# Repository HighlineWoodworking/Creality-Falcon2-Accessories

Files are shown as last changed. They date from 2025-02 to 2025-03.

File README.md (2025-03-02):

# Creality-Falcon2-Accessories
Accessories for a [Creality Falcon2 Laser](https://www.creality.com/products/creality-falcon2-22w).

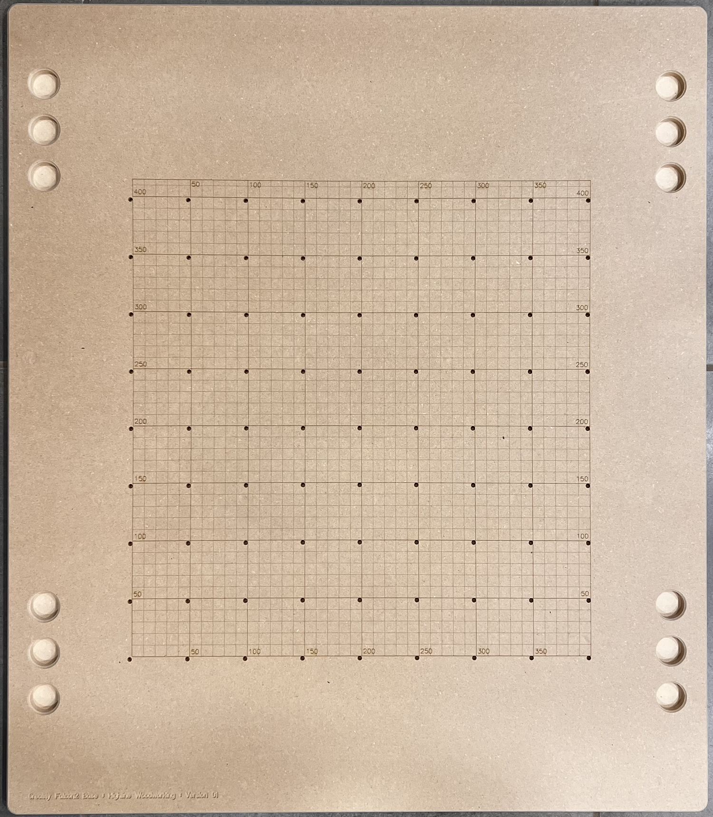
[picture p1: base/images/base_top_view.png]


[Base](base/README.md)

## Using

Projects and files are 100% free to use under [CC0](https://creativecommons.org/public-domain/cc0/).

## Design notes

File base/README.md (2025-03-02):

# Creality Falcon2 Base

Provides a secure foundation for a [Creality Falcon2 Laser Frame](https://www.creality.com/products/creality-falcon2-22w) and supports precise, repeatable positioning of work pieces.

Falcon2 base 3d rendering.

## Tools and Materials

* CNC machine capable of machining a 26 x 30 inch piece
* 1/2 inch MDF 650 x 744mm which leaves a 20mm margin on each edge for hold-down clamps
* 1/4 inch end-mill, only absolutely required bit, good examples:
  * [Cadence Manufacturing "The Jenny"](https://www.cadencemfgdesign.com/product-page/the-jenny-bit-8675309)
  * [Woodpeckers US2102C](https://www.woodpeck.com/ultra-shear-quarter-inch-spiral-compression-bits.html)
* 90 deg v-bit
  * [Amana RC-45711](https://www.amazon.com/Amana-RC-45711-Insert-Carbide-Groove/dp/B003DCMDRU)
* 4mm up-cut
  * [Woodpeckers US204MU](https://www.woodpeck.com/ultra-shear-metric-mortising-bits-for-domino-tenons.html)
* 4mm alignment pins
  * [Amazon Asamuyu stainless steel pins](https://www.amazon.com/Stainless-Shelves-Hardware-Support-Fastener/dp/B0D1VHPK3Y?th=1) - very tight fit
  * [Amazon uxcell 4mm wooden dowels](https://www.amazon.com/uxcell-Beveled-Hardwood-Woodworking-Furniture/dp/B0BJTX5PRV/ref=sr_1_40)
  
## Machining

### 90deg V-bit

* softens edges, makes feet easier to insert, adds label
* machine along the vectors
* layers ```Outlines and Feet Insets``` final depth 1mm
* layer ```Highline Woodworking``` 0.2mm (skip entirely if you don't want the text label or change to your own)

### 4mm Up-Cut

* 5mm spaced holes for 4mm alignment pins
* layer ```Alignment Holes``` final depth 5mm
* drill peck holes

### 1/4 inch End-Mill

* cuts insets for feet and the final outline for the piece
* layer ```Feet Insets``` area clear inside the circles, final depth 8mm
* layer ```Outlines``` cut outside the vectors, 13.1mm final depth
  * add bridges or other supports
  * example bridges: 8 x 30mm long x 1mm thick
 
### Reference Grid

See [Engraving the Reference Grid](reference_grid.md)

## Files

* base_v01.art = [Carveco Maker](https://carveco.com/carveco-software-range/carveco-maker/) source file
* base_v01.dxf = [DXF](https://en.wikipedia.org/wiki/AutoCAD_DXF) exported source file
* base_v01.dwg = AutoCad drawing file created with [Siemens Solid Edge 2D](https://resources.sw.siemens.com/en-US/download-free-2d-cad-software/)
* laser_grid.nc = [G-code](https://en.wikipedia.org/wiki/G-code) file to burn a reference grid into the completed MDF base

## Dimensions

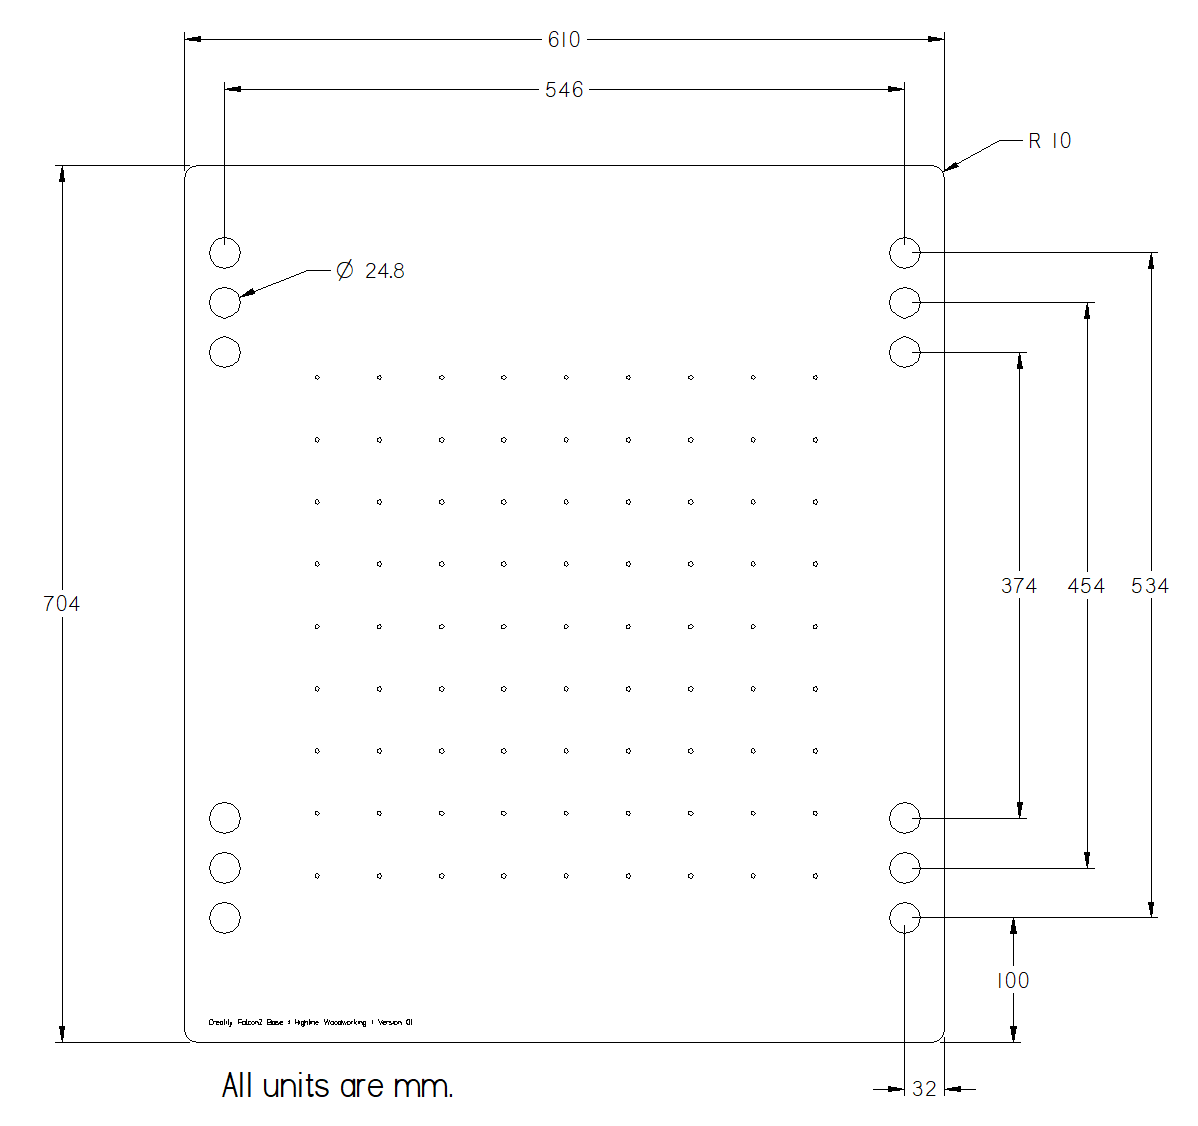
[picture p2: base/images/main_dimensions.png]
Main dimensions.


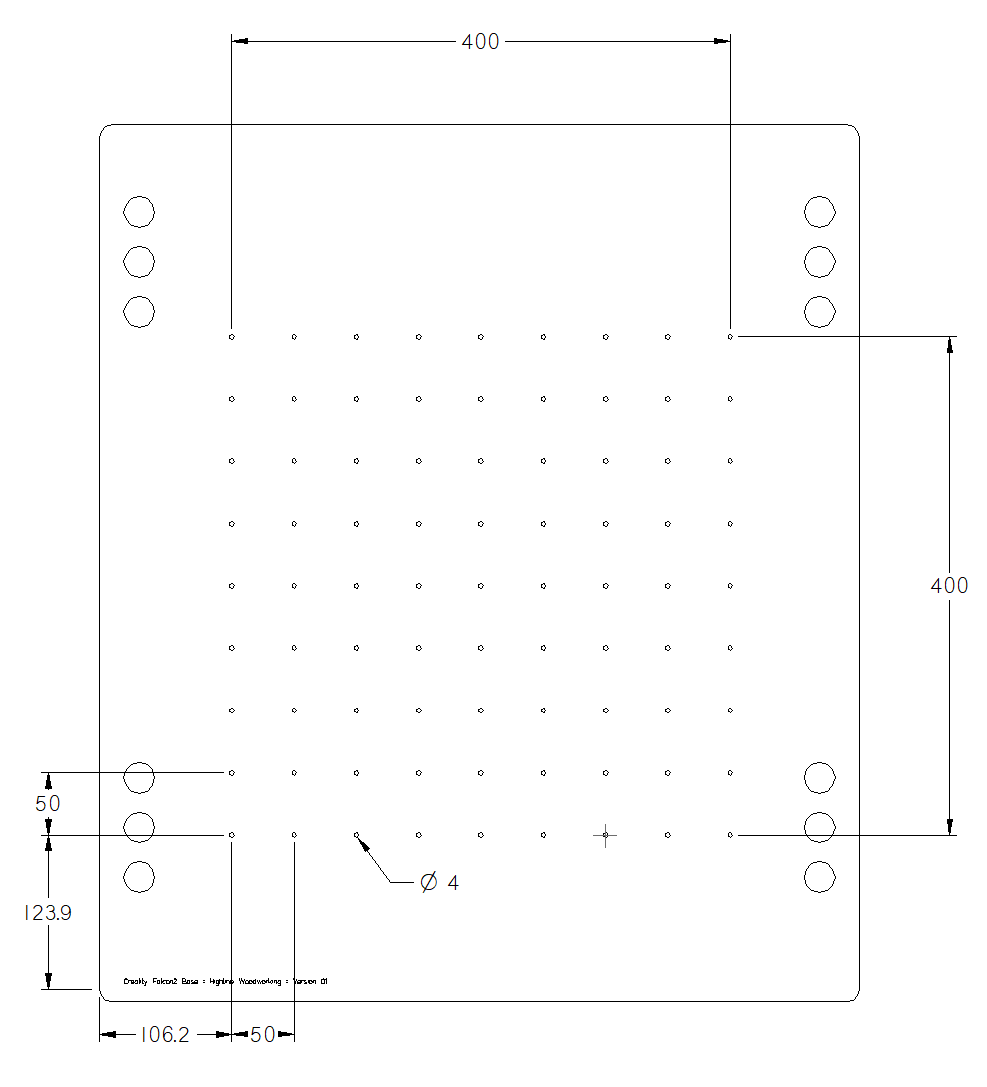
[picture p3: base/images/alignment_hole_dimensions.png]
Alignment hole dimensions.


## Images

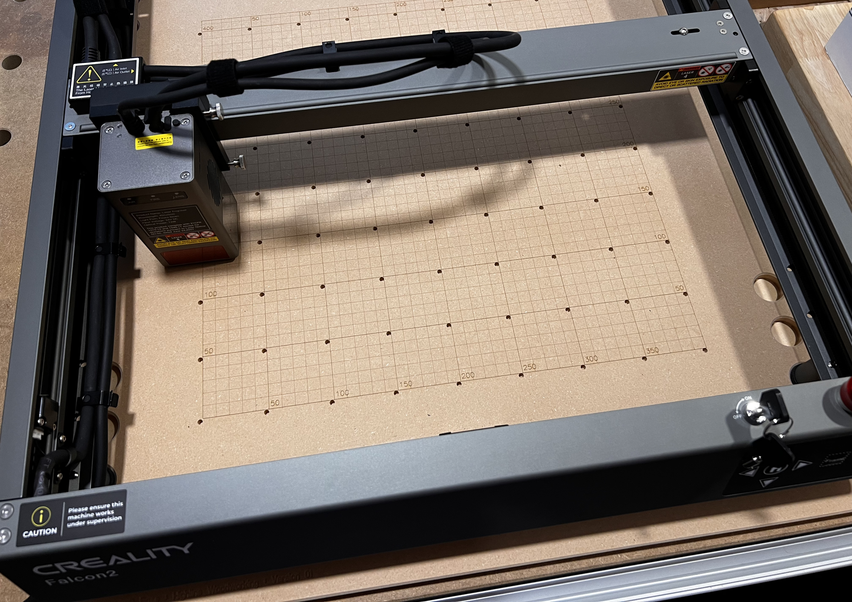
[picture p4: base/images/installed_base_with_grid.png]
Installed base.


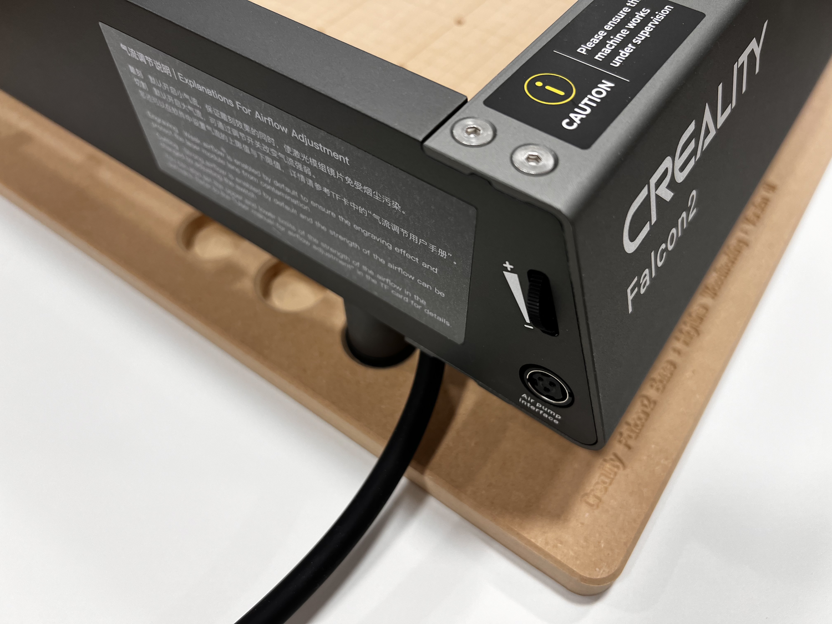
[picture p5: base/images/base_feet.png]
Base feet.


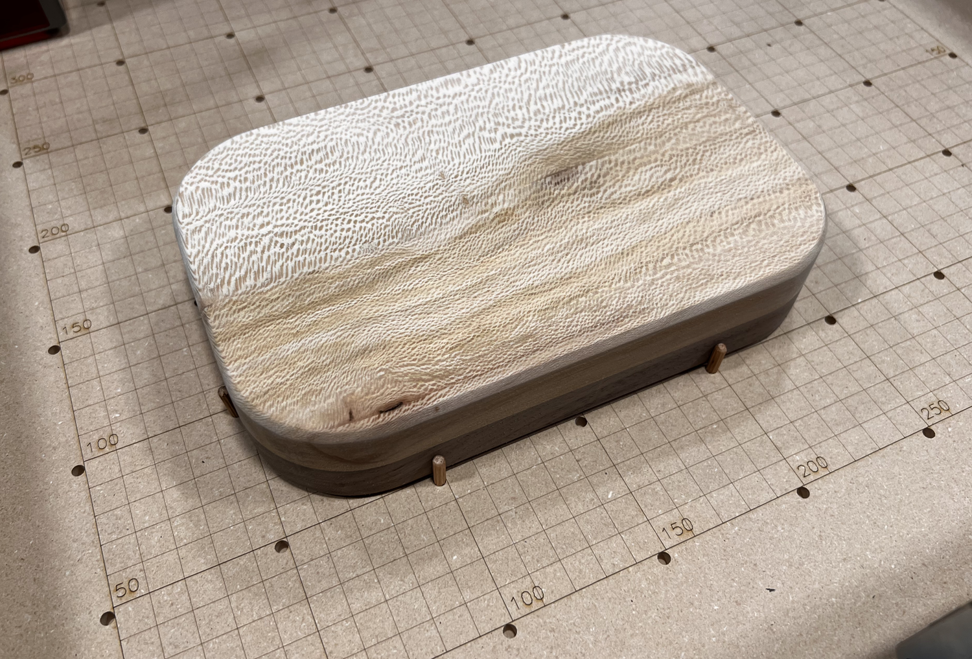
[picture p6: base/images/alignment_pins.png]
Alignment pins.


## Versions

* v01 | 10-Feb-2025 | inital post

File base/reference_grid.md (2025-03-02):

# Engraving the Reference Grid

A G-code file to engrave a reference grid on the MDF base is included with the project.  The grid in combination with the alignment holes/pins can be used to precisely position and engrave a piece using known coordinates.  For example, in the figure below the lower-left corner of the piece is positioned at exactly 50,50 (mm).  The reference grid will be 400 x 415mm which covers the extents of the Falcon2 working area.

Alignment pins.

1. Mount the Falcon2 on the base, and set the laser height for engraving.
2. Open [LaserGRBL](https://lasergrbl.com/), open the reference grid G-code file and connect to the Falcon2.
3. Click the buttons 1 then 2 in LaserGRBL per the image below.  This will send the laser to home and zero it at home.
4. Send the file to the Falcon2.

LaserGRBL steps.

# Alignment Accuracy

In my one test the reference grid should track the alignment holes within ~1mm across the working area which I suspect is the accuracy of the Falcon2.  If you find otherwise would be curious to know how much it changes and any ideas why.

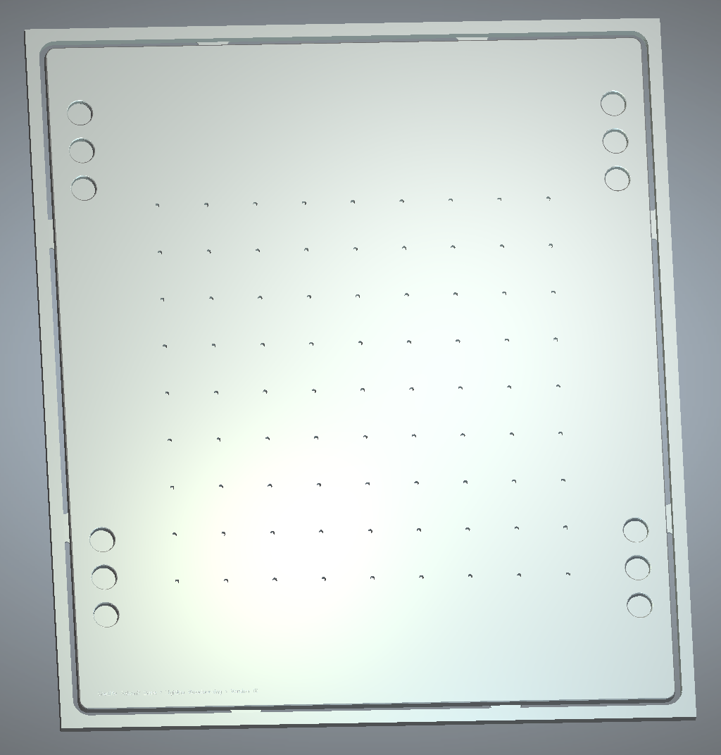
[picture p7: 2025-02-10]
base/images/3d_rendering.png

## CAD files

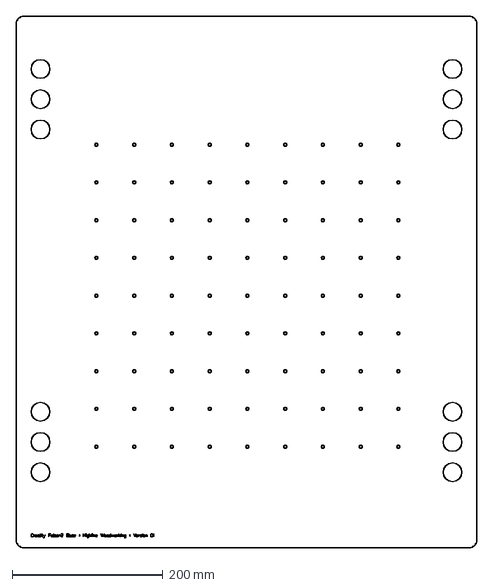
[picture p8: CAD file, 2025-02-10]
base/base_v01.dxf
610.0 x 704.0 mm

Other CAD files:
base/base_v01.dwg

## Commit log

2025-02-10 Added DXF export.
    [base_v01.dxf]
2025-02-14 Modified DWG, added dimension images.
    [base_v01.dwg]
2025-03-02 Updated LaserGRBL image.
2025-04-05 Added denser set of alignment holes to base lower-left, started clamps.
